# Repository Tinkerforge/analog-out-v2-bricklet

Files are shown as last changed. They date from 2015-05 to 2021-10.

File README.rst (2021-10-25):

Analog Out Bricklet 2.0
=======================

This repository contains the firmware source code and the hardware design
files. The documentation generator configs can be found at
https://github.com/Tinkerforge/generators

Repository Content
------------------

software/:
 * examples/: Examples for all supported languages
 * build/: Compiled files
 * src/: Source code of firmware
 * Makefile: Makefile to build project

hardware/:
 * Contains KiCad project files and additionally schematics as PDF

datasheets/:
 * Contains datasheets for sensors and complex ICs that are used

Hardware
--------

The hardware is designed with the open source EDA Suite KiCad
(http://www.kicad.org). Before you are able to open the files,
you have to install the Tinkerforge kicad-libraries
(https://github.com/Tinkerforge/kicad-libraries). You can either clone
them directly in hardware/ or clone them in a separate folder and
symlink them into hardware/
(ln -s kicad_path/kicad-libraries project_path/hardware). After that you
can open the .pro file in hardware/ with KiCad and from there view and
modify the schematics and the PCB layout.

Software
--------

If you want to do your own Brick/Bricklet firmware development we highly
recommend that you use our build environment setup script and read the
tutorial (https://www.tinkerforge.com/en/doc/Tutorials/Tutorial_Build_Environment/Tutorial.html).

To compile the C code we recommend you to install the newest GNU Arm Embedded
Toolchain (https://launchpad.net/gcc-arm-embedded/+download).
You also need to install bricklib (https://github.com/Tinkerforge/bricklib)
and brickletlib (https://github.com/Tinkerforge/brickletlib).

You can either clone it directly in software/src/ or clone it in a
separate folder and symlink it into software/src/
(ln -s bricklib_path/bricklib project_path/software/src/ and
ln -s brickletlib_path/brickletlib project_path/software/src/).
Finally make sure to have CMake installed
(http://www.cmake.org/cmake/resources/software.html).

After that you can build the firmware by invoking make in software/.
The firmware (.bin) can then be found in software/build/ and uploaded
with brickv (click button "Flashing" on start screen).

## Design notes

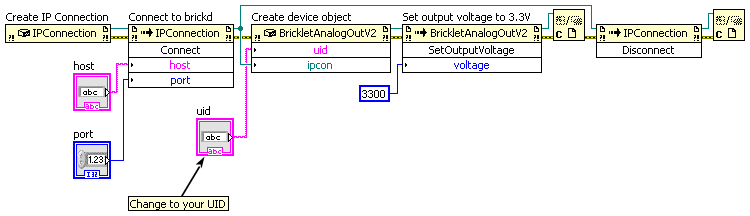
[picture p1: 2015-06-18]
software/examples/labview/Example Simple.vi.png

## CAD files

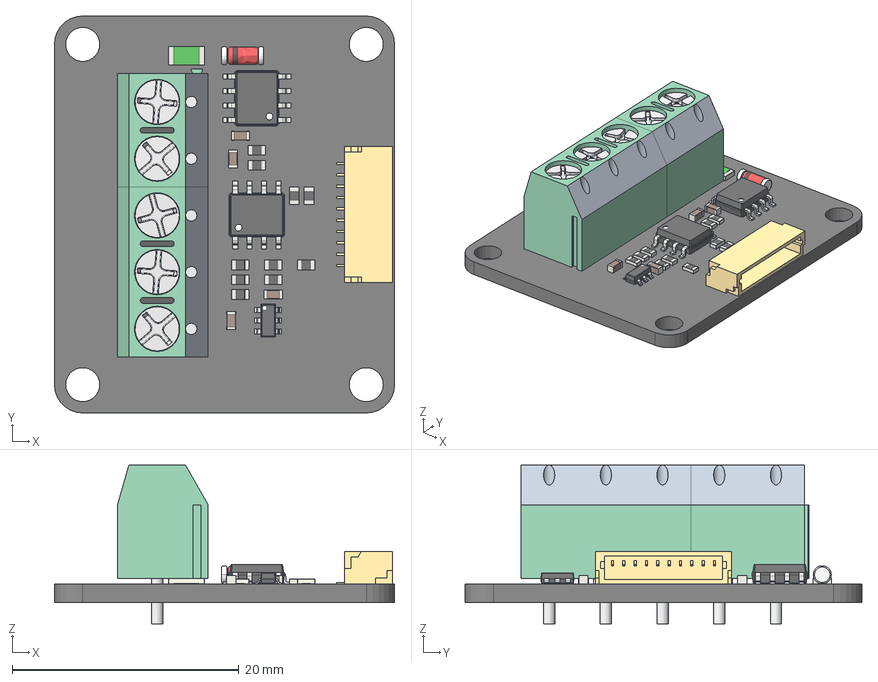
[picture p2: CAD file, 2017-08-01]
hardware/analog-out-v2.step
30.0 x 35.0 x 14.0 mm

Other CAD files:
hardware/analog-out-v2.FCStd

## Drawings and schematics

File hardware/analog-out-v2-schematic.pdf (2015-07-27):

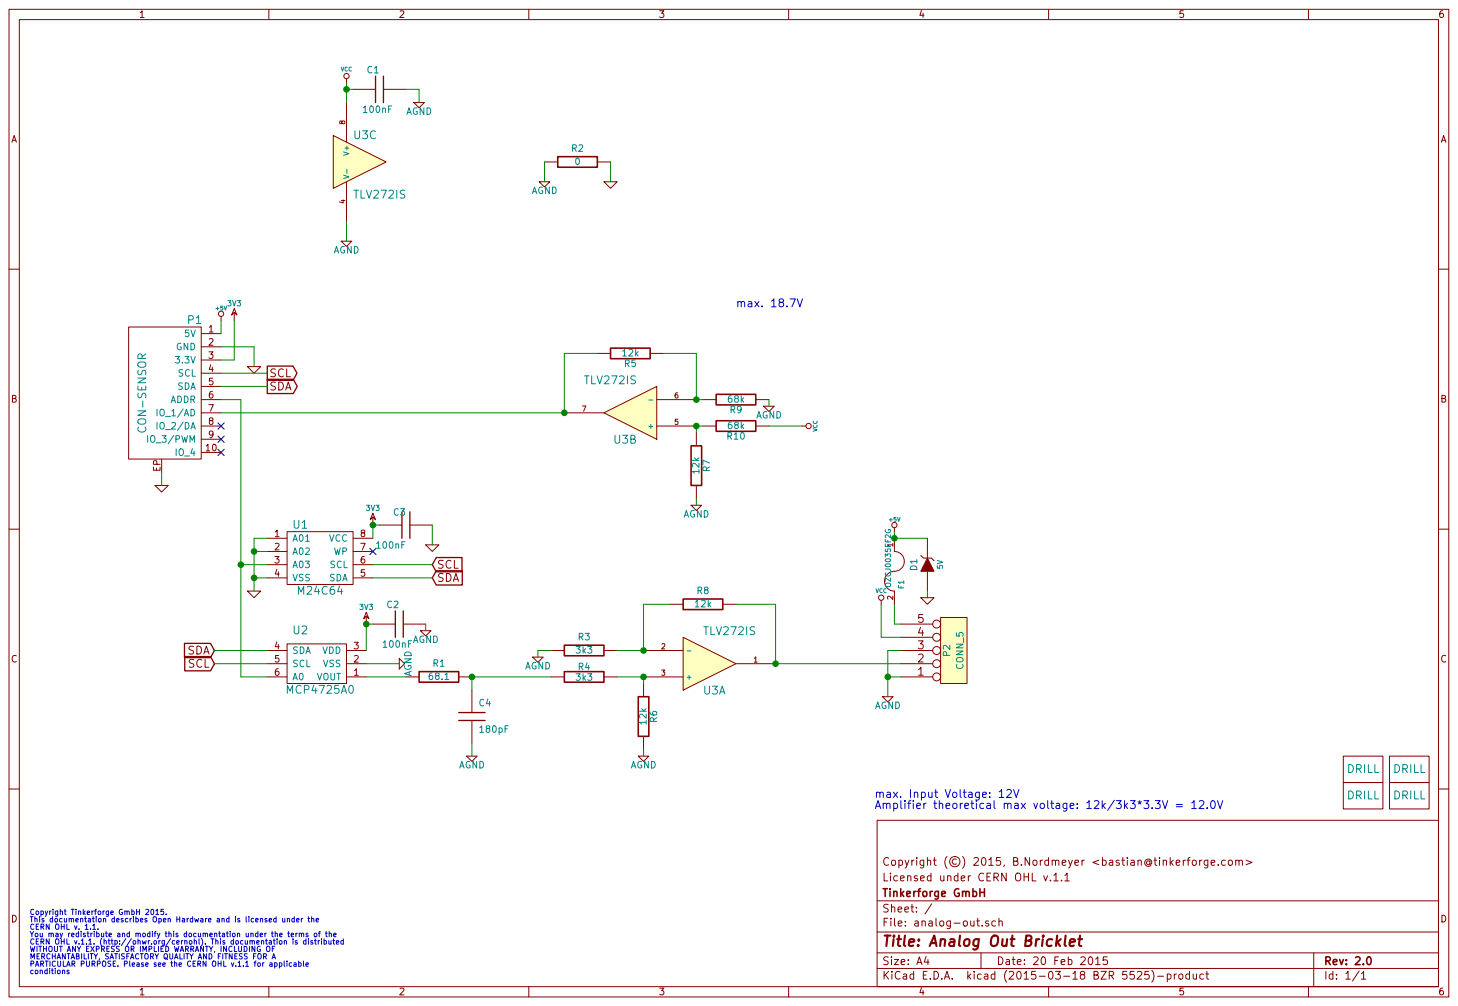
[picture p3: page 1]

Amplifier theoretical max voltage: 12k/3k3*3.3V = 12.0V max. 18.7V

File: analog-out.sch Sheet: / Tinkerforge GmbH

Copyright Tinkerforge GmbH 2015. This documentation describes Open Hardware and is licensed under the CERN OHL v. 1.1. You may redistribute and modify this documentation under the terms of the CERN OHL v.1.1. (http://ohwr.org/cernohl). This documentation is distributed WITHOUT ANY EXPRESS OR IMPLIED WARRANTY, INCLUDING OF MERCHANTABILITY, SATISFACTORY QUALITY AND FITNESS FOR A

Id: 1/1 Title: Analog Out Bricklet

PARTICULAR PURPOSE. Please see the CERN OHL v.1.1 for applicable

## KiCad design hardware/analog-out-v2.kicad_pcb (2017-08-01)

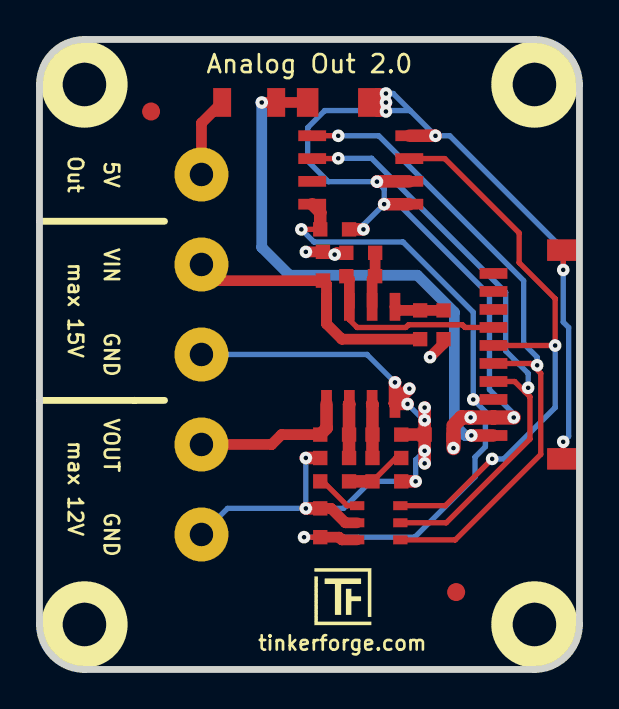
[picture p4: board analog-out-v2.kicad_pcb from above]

Board: 2 copper layers, 30.0 x 35.0 mm, 30 parts (0 on the bottom side), 17 nets.

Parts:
C1, C2, C3: 100nF; C0603
C4: 180pF; C0603
D1: 5V; MiniMelf
F1: OZCJ0035FF2G; F1206
Fiducial_Mark: VAL**; Fiducial_Mark
Fiducial_Mark#2: VAL**; Fiducial_Mark
P1: CON-SENSOR
P2: CONN_5; AKL_5_5
R1: 68.1; R0603
R2: 0; R0603
R3, R4: 3k3; R0603
R5, R6, R7, R8: 12k; R0603
R9, R10: 68k; R0603
Ref**: Val**; Logo_31x31
U1: M24C64; SOIC8
U2: MCP4725A0; SOT23-6
U3: TLV272IS; SOIC8
U4, U5, U6, U7: DRILL; DRILL_NP
VAL: CE_5mm
VAL#2: WEEE_7mm

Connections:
3V3: C2.1, C3.1, P1.3, U1.8, U2.3
+5V: D1.2, F1.1, P1.1
AGND: C1.2, C2.2, C4.2, P2.1, P2.3, R2.2, R3.2, R6.2, R7.2, R9.1, U2.2, U3.4
GND: C3.2, D1.1, P1.2, P1.EP, R2.1, U1.1, U1.2, U1.4
unnamed: C4.1, R1.1, R4.1
unnamed: F1.2, P2.5
unnamed: P1.6, U1.3, U2.6
unnamed: P1.7, R5.2, U3.7
unnamed: P2.2, R8.1, U3.1
unnamed: R1.2, U2.1
unnamed: R3.1, R8.2, U3.2
unnamed: R4.2, R6.1, U3.3
unnamed: R5.1, R9.2, U3.6
unnamed: R7.1, R10.2, U3.5
SCL: P1.4, U1.6, U2.5
SDA: P1.5, U1.5, U2.4
VCC: C1.1, P2.4, R10.1, U3.8

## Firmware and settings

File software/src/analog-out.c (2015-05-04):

/* analog-out-v2-bricklet
 * Copyright (C) 2015 Olaf Lüke <olaf@tinkerforge.com>
 *
 * analog-out.c: Implementation of Analog Out 2.0 Bricklet messages
 *
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
 * You should have received a copy of the GNU Lesser General Public
 * License along with this library; if not, write to the
 * Free Software Foundation, Inc., 59 Temple Place - Suite 330,
 * Boston, MA 02111-1307, USA.
 */

#include "analog-out.h"

#include "bricklib/bricklet/bricklet_communication.h"
#include "bricklib/utility/util_definitions.h"
#include "bricklib/utility/init.h"
#include "bricklib/drivers/adc/adc.h"

#include "brickletlib/bricklet_debug.h"
#include "brickletlib/bricklet_entry.h"

#include "config.h"

void constructor(void) {
	_Static_assert(sizeof(BrickContext) <= BRICKLET_CONTEXT_MAX_SIZE, "BrickContext too big");

	adc_channel_enable(BS->adc_channel);
	BC->counter = 0;
	BC->input_voltage_sum = 0;

    PIN_REF_VOLTAGE.type = PIO_INPUT;
    BA->PIO_Configure(&PIN_REF_VOLTAGE, 1);

	update();
}

void destructor(void) {
	adc_channel_disable(BS->adc_channel);
}

void invocation(const ComType com, const uint8_t *data) {
	switch(((StandardMessage*)data)->header.fid) {
		case FID_SET_OUTPUT_VOLTAGE: {
			set_output_voltage(com, (SetOutputVoltage*)data);
			break;
		}

		case FID_GET_OUTPUT_VOLTAGE: {
			get_output_voltage(com, (GetOutputVoltage*)data);
			break;
		}

		case FID_GET_INPUT_VOLTAGE: {
			get_input_voltage(com, (GetInputVoltage*)data);
			break;
		}

		default: {
			BA->com_return_error(data, sizeof(MessageHeader), MESSAGE_ERROR_CODE_NOT_SUPPORTED, com);
			break;
		}
	}
}

void tick(const uint8_t tick_type) {
	if(tick_type & TICK_TASK_TYPE_CALCULATION) {
		BC->counter++;
		BC->input_voltage_sum += BA->adc_channel_get_data(BS->adc_channel);
		if(BC->counter == 0) {
			BC->last_input_voltage_sum = BC->input_voltage_sum;
			BC->input_voltage_sum = 0;
		}
	}
}

void set_output_voltage(const ComType com, const SetOutputVoltage *data) {
	if(data->voltage > ANALOG_MAX_VOLTAGE) {
		BA->com_return_error(data, sizeof(MessageHeader), MESSAGE_ERROR_CODE_INVALID_PARAMETER, com);
		return;
	}

	BC->last_output_voltage = data->voltage;
	update();

	logbli("set_output_voltage: %d\n\r", data->voltage);

	BA->com_return_setter(com, data);
}

void get_output_voltage(const ComType com, const GetOutputVoltage *data) {
	GetOutputVoltageReturn govr;
	govr.header        = data->header;
	govr.header.length = sizeof(GetOutputVoltageReturn);
	govr.voltage       = BC->last_output_voltage;

	BA->send_blocking_with_timeout(&govr, sizeof(GetOutputVoltageReturn), com);
	logbli("get_output_voltage: %d\n\r", govr.voltage);
}

void get_input_voltage(const ComType com, const GetInputVoltage *data) {
	GetInputVoltageReturn givr;
	givr.header        = data->header;
	givr.header.length = sizeof(GetInputVoltageReturn);
	// voltage = input*3300*68/(4095*12*256) = input*935/52416
	givr.voltage       = BC->last_input_voltage_sum*935/52416;

	BA->send_blocking_with_timeout(&givr, sizeof(GetInputVoltageReturn), com);
	logbli("get_input_voltage: %d\n\r", givr.voltage);
}

void update(void) {
	uint8_t address;
	if(BS->address == I2C_EEPROM_ADDRESS_HIGH) {
		address = I2C_ADDRESS_HIGH;
	} else {
		address = I2C_ADDRESS_LOW;
	}

	const uint8_t port = BS->port - 'a';
	const uint16_t output_voltage = BC->last_output_voltage*4095/12000;

	uint8_t byte1 = output_voltage >> 8;
	uint8_t byte2 = output_voltage & 0xFF;

	logbli("update %d\n\r", output_voltage);

	BA->mutex_take(*BA->mutex_twi_bricklet, MUTEX_BLOCKING);
	BA->bricklet_select(port);
    BA->TWID_Write(BA->twid, address, byte1, 1, &byte2, 1, NULL);
    BA->bricklet_deselect(port);
    BA->mutex_give(*BA->mutex_twi_bricklet);
}

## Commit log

2015-03-03 Add first adaption from V1 to V2
    Missing:
    - Correct voltage input calculation (currently still for V1)
    - API to get and force specified voltage for input
    [analog-out.c, analog-out.h]
2015-03-27 checkin of hardware files of V2 version
    [analog-out.kicad_pcb, analog-out.sch]
2015-03-30 change output voltage to max 12V
    [analog-out.kicad_pcb, analog-out.sch]
2015-03-31 add second ground connector add fuse and z-diode for 5V rail
    [analog-out.kicad_pcb, analog-out.sch]
2015-03-31 missing changes from last commit
    [analog-out.kicad_pcb]
2015-04-02 order version
    [analog-out.kicad_pcb]
2015-04-02 change port description
    [analog-out.kicad_pcb]
2015-04-16 specify fuse
    [analog-out.kicad_pcb, analog-out.sch]
2015-04-24 change voltage devider to opamp differential amplifier
    [analog-out.kicad_pcb, analog-out.sch]
2015-04-24 drc executed
    [analog-out.kicad_pcb]
2015-05-04 Calculate voltage as used in production version
2015-07-27 adapt schematic acording to symbol change, add PDF schematic
    [analog-out.sch]
2015-08-07 Use full device class name in Python examples
2016-05-18 c: Add missing device destroy call
2017-08-01 use tinkerforge symbols instead of kicad symbols
    [analog-out.kicad_pcb, analog-out.sch]
2017-08-01 Add 3d information (final)
    [analog-out.kicad_pcb, analog-out.sch]
2017-08-01 Add 3d model (*.step & *.FCStd)
    [analog-out.step, analog_out.FCStd]
2017-08-03 Rename *.FCStd file
    [analog-out.FCStd]
2018-02-20 Cleanup KiCad libraries config
    Ensure LibDir=kicad-libraries and LibName1=tinkerforge.
    Remove special library.
2018-05-11 Rename files
    [analog-out-v2.FCStd, analog-out-v2.kicad_pcb, analog-out-v2.sch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]
2021-10-25 Update KiCad link
    https://www.kicad.org/blog/2021/10/Avoid-links-to-former-kicad-domain/

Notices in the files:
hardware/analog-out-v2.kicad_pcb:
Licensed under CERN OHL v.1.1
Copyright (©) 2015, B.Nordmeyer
